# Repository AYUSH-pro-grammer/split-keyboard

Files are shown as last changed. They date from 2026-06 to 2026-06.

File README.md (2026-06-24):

# Split Keyboard

Split keyboard created in kicad and cad

## What is this project

This is a split keyboard. It is divided into 2 parts.
I designed it to gain some experience in pcb design, cad modeling and firmware development.
It has 22 keys per side, oled display, and rotary encoder.

## Why I made it

I want to design my own keyboard to gain experience in hardware project.
I got a lot of useful information about creating schematics, pcb routing, footprints, cad case modeling and file structure on github.

## what is inside

- split keyboard pcb
- cad case 
- firmware file
- gerber files
- project images
- bom csv

## Images

### Schematic Left

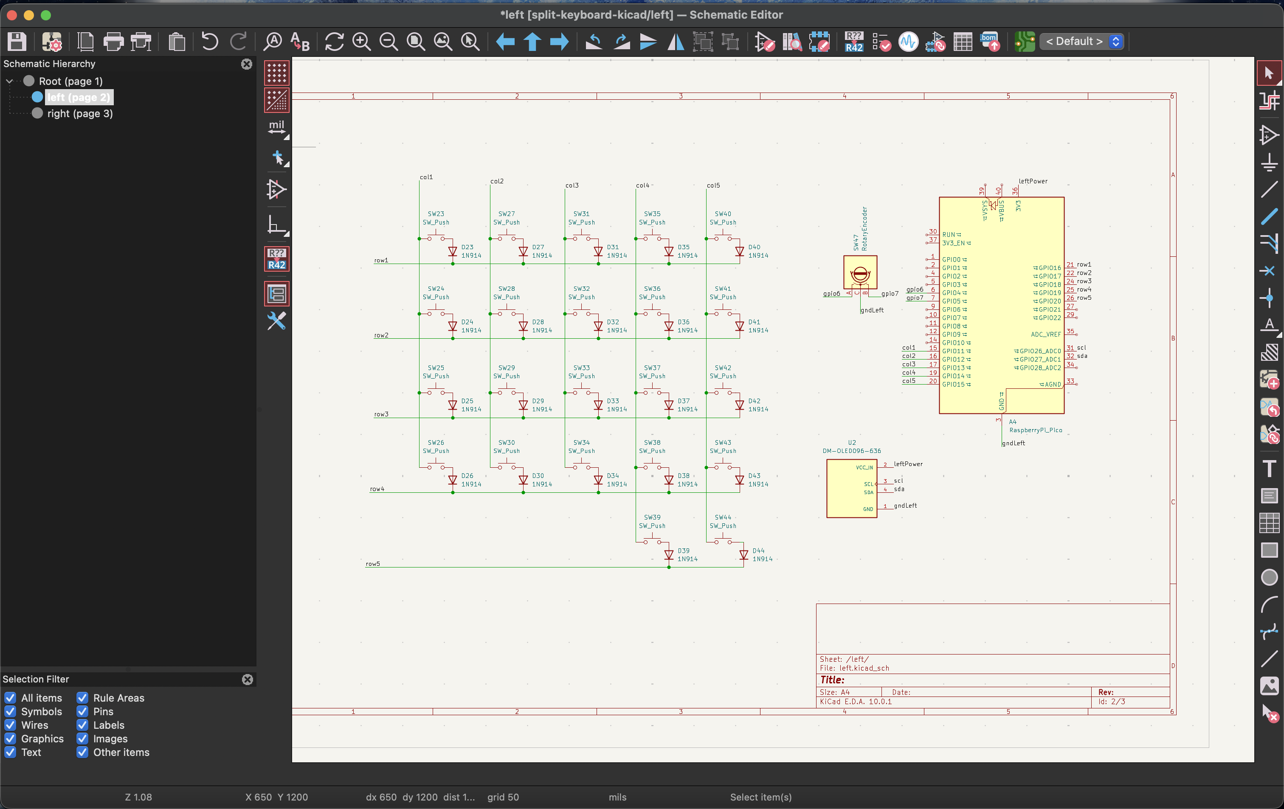
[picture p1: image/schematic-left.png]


### Schematic Right

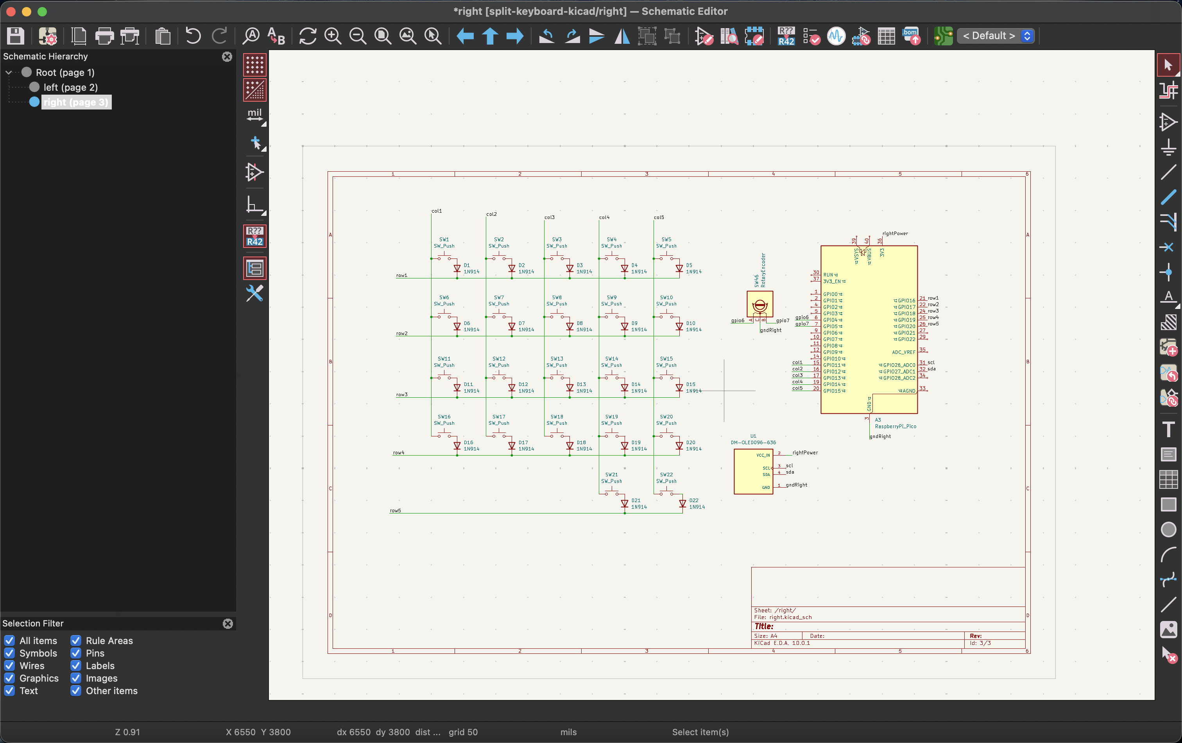
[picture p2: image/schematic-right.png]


### PCB Routing

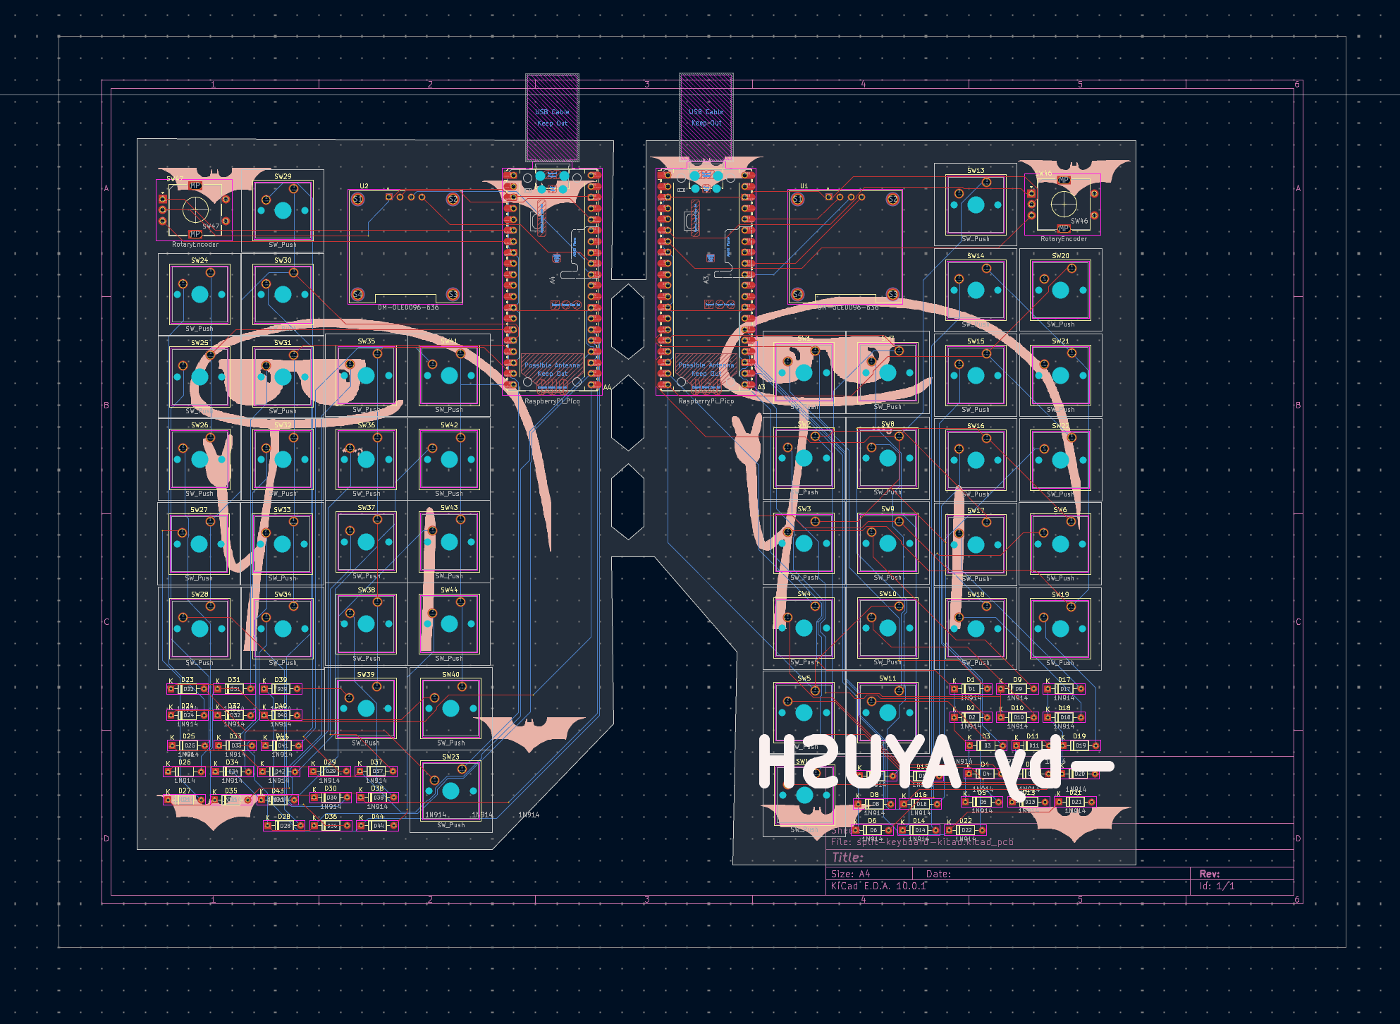
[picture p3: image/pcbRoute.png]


### PCB 3D Front

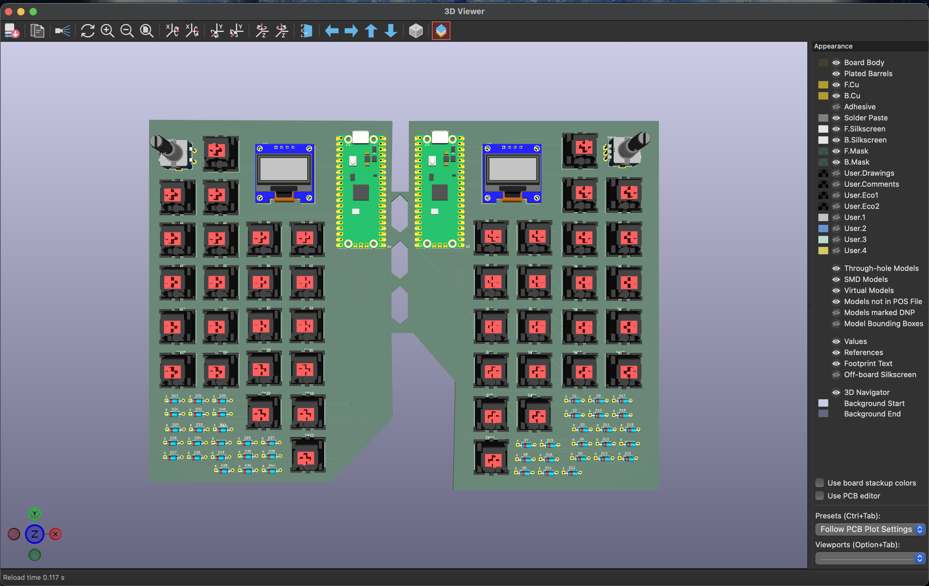
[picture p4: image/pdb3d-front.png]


### PCB 3D Back

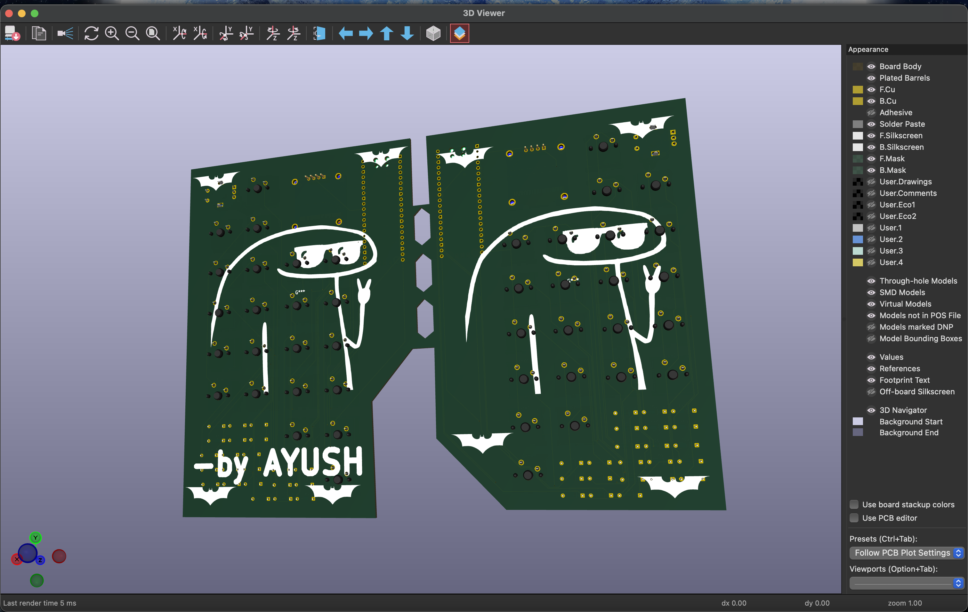
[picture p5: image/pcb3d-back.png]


### 3D 1

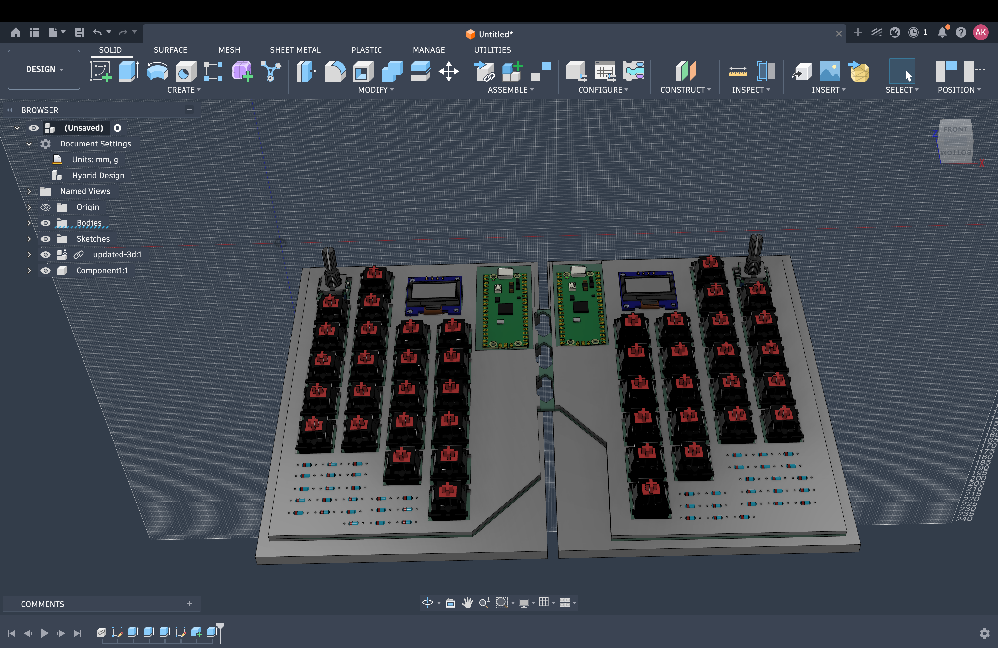
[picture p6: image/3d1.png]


### 3D 2

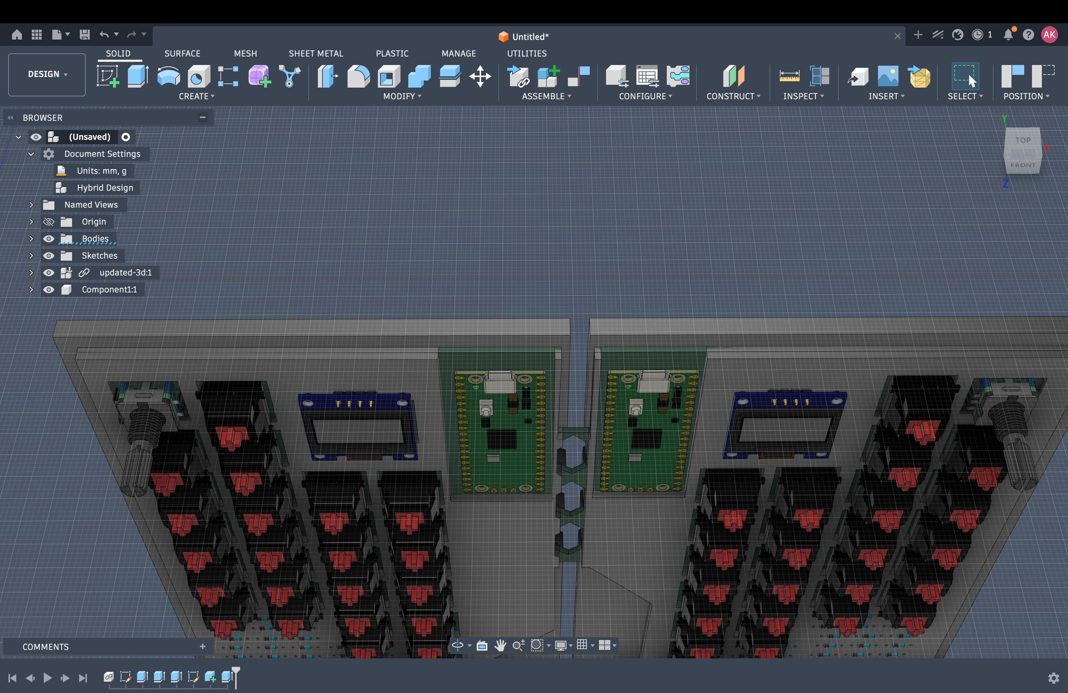
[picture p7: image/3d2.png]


### PCB Order

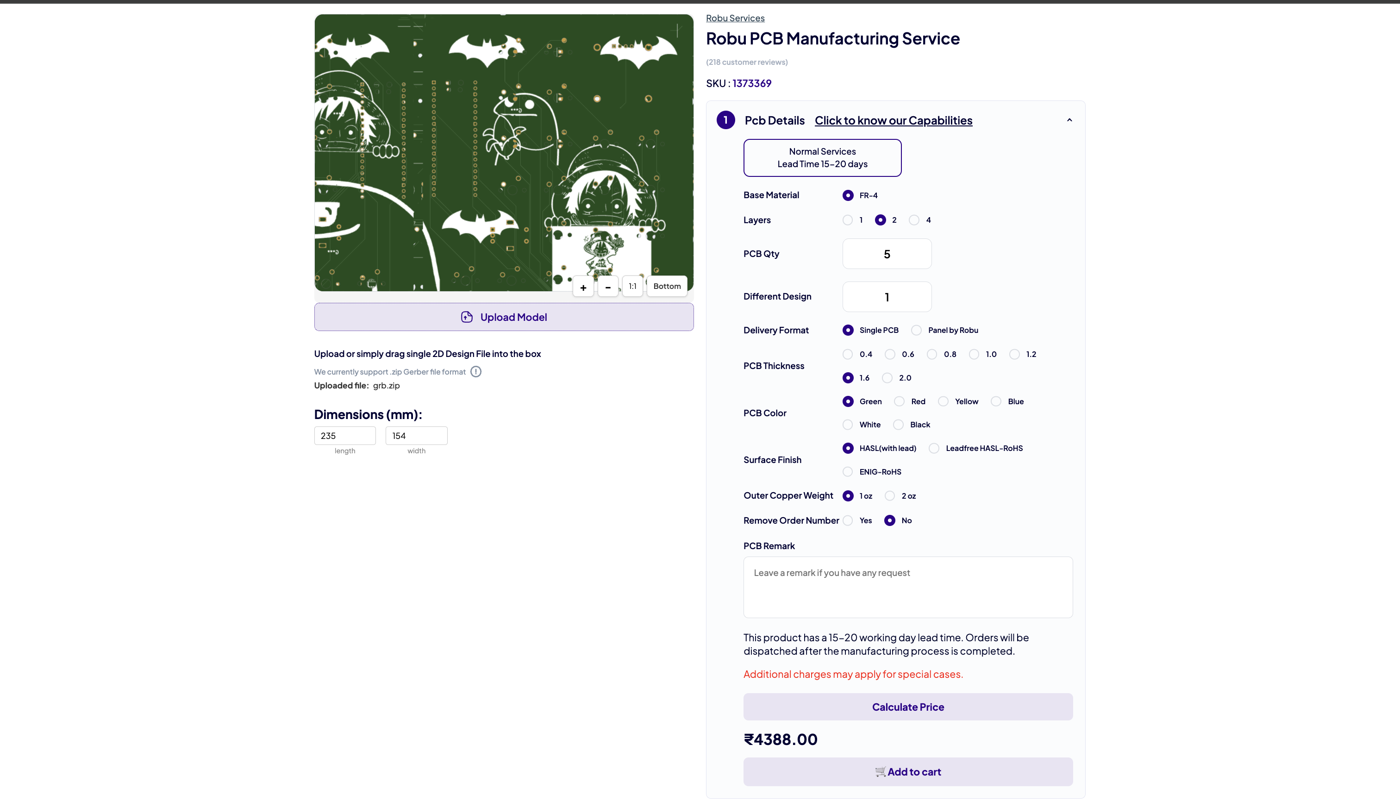
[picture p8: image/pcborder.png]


### Keycaps

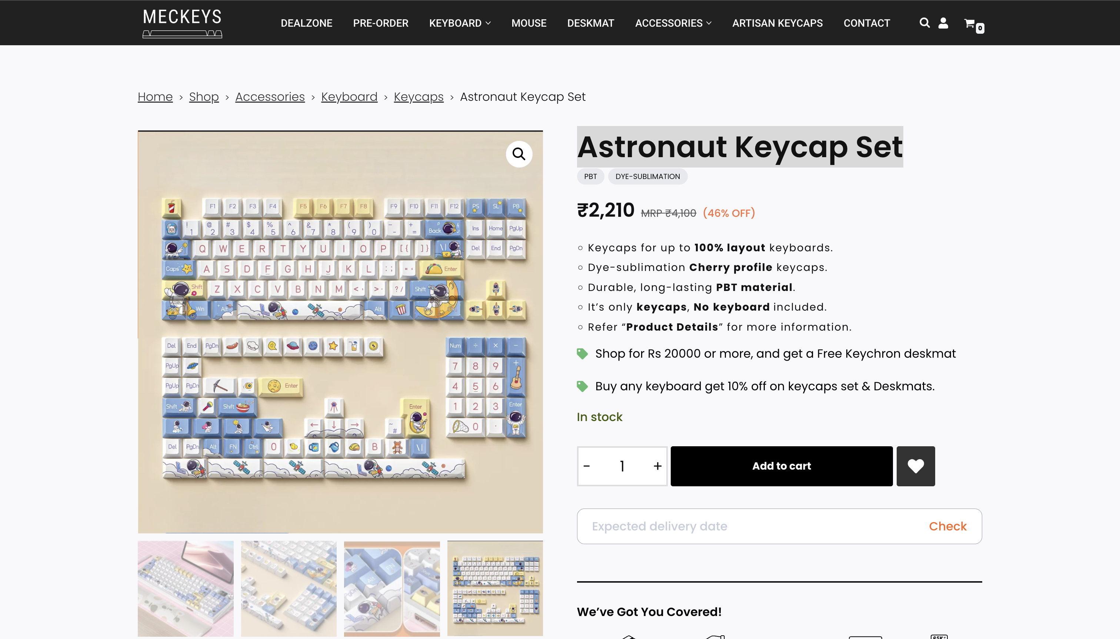
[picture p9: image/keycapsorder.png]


### Cherry MX Switches

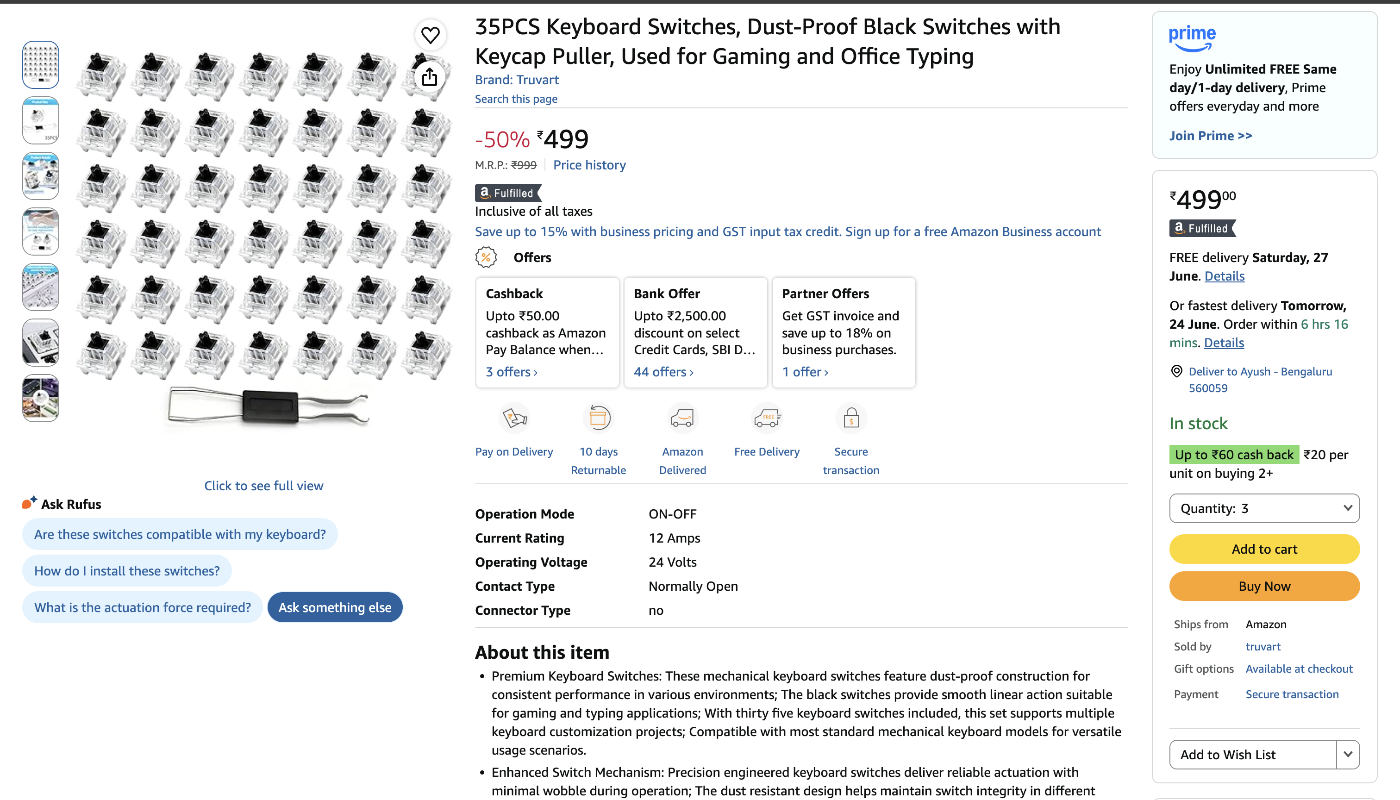
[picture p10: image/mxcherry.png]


### Repository Organization

```text
split-keyboard/
│
├── README.md
├── split-keyboard-bom.csv
│
├── cad/
│   ├── assembled.f3z
│   ├── assembled.step
│   └── pcb3d[pcb only].step
│
├── grb/
│   ├── split-keyboard-kicad-B_Cu.gbr
│   ├── split-keyboard-kicad-B_Mask.gbr
│   ├── split-keyboard-kicad-B_Paste.gbr
│   ├── split-keyboard-kicad-B_Silkscreen.gbr
│   ├── split-keyboard-kicad-Edge_Cuts.gbr
│   ├── split-keyboard-kicad-F_Cu.gbr
│   ├── split-keyboard-kicad-F_Mask.gbr
│   ├── split-keyboard-kicad-F_Paste.gbr
│   ├── split-keyboard-kicad-F_Silkscreen.gbr
│   ├── split-keyboard-kicad-NPTH.drl
│   ├── split-keyboard-kicad-PTH.drl
│   └── split-keyboard-kicad-job.gbr

```

## Features

* split keyboard design
* 22 keys on each side
* oled display
* 2 rotary encoders
* custom pcb designed in kicad
* custom cad case
* raspberry pi pico controller
* firmware written in c++

## 3D Model

### Full Keyboard Assembly

Full Keyboard Assembly

IMAGE COMMING SOONN AFTER BUILD...

this is the complete 3d model of the split keyboard with all major components placed inside the design. the model was created to verify the fit of the pcb, switches, display, rotary encoders, and case before manufacturing.

## Firmware

the firmware files for this project are available in the `split_keyboard_firmware/` folder.

currently the firmware is still being developed and tested. basic project structure, display examples, and source files have already been added to the repository.

## build notes

- i used kicad for my schematics and PCB design
- i designed the keyboard case in cad
- i exported gerber files for manufacture
- i kept the design simple to make it easy to build and code

## BOM

| Name | Purpose | Quantity | Total Cost (USD) | Link | Distributor |
| --- | --- | ---: | ---: | --- | --- |
| raspberry pi pico board | devboard to code on | 2 | $8.11 | https://robu.in/product/raspberry-pi-pico/ | robu |
| rotary encoder | knob control | 2 | $4.00 | https://robu.in/product/hongyan-ec11h-7ce15p1zy15f7-rotary-encoder-with-push-button-switch-vertical-plug-in/ | robu |
| pcb | to soilder all things onn | 1 | $46.00 | https://robu.in/product/online-pcb-manufacturing-service/ | robu |
| keycaps | to put above mx keys which give more surface area to click the button | 1 | $22.00 | https://meckeys.com/shop/accessories/keyboard-accessories/keycaps/astronaut-keycap-set/ | meckeys |
| mx cherry keys | to make button works, it is the buttons to press | 44 | $17.00 | https://www.amazon.in/Keyboard-Switches-Dust-Proof-Keycap-Puller/dp/B0GZVJZP6V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 | amazon |
| 1N4148 diodes | key matrix isolation | 44 | $3.00 | https://robu.in/product/diode-1n4148/ | robu |

## note

this project is still being worked on, and i will keep improving the case, layout, and code.

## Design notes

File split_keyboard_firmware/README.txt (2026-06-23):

Split Keyboard Firmware Package

File names:
- main.cpp      : Split keyboard firmware for a single Pico per half
- oled_demo.cpp : OLED demo sketch
- platformio.ini : PlatformIO Arduino project file

Pin configuration according to your schematic:
- Row pins: GPIO16, 17, 18, 19, 20
- Col pins: GPIO11, 12, 13, 14, 15
- Rotary encoder pins: GPIO6, GPIO7
- OLED I2C: GPIO26 = SCL, GPIO27 = SDA
- OLED address: 0x3C

Tips:
- Flash the same firmware on both Picos.
- Define SIDE_LEFT = 1 for the left half and 0 for the right half.
- It is easy to modify the keymap arrays if you have another keymap in mind.
- You need to switch the scanning mechanism in case of reverse diodes.

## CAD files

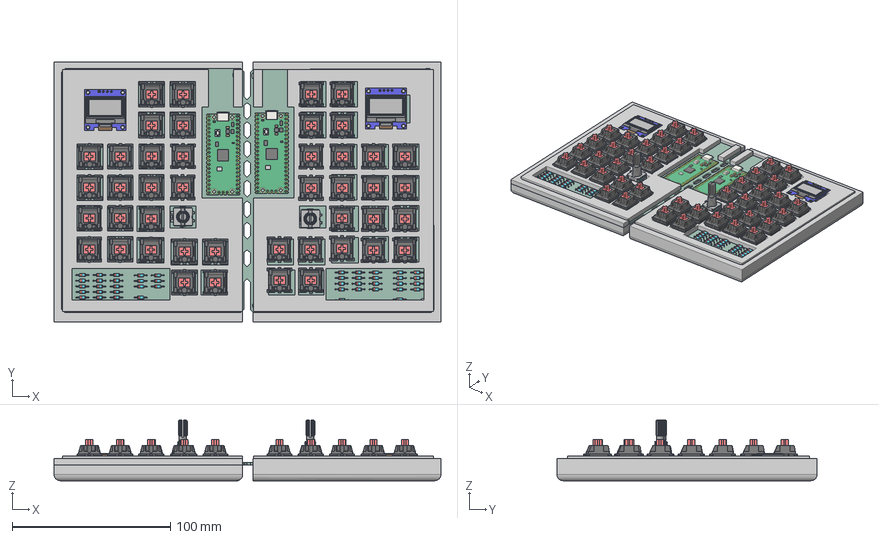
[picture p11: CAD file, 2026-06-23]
cad/assembled.step
244.3 x 164.2 x 38.2 mm

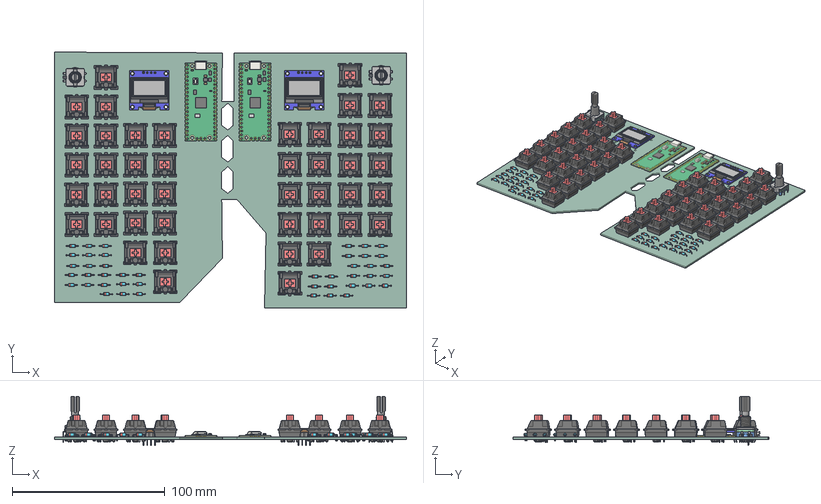
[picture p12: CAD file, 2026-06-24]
cad/3d-PCB-ONLY.step
230.5 x 167.5 x 32.3 mm
D_DO-35_SOD27_P7.62mm_Horizontal x 44
RaspberryPi_Pico_Module_KiCad x 2
DM-OLED096-636_Module x 2
DM-OLED096-636_Panel x 2
EC11_Rotary_Encoder_Switched x 2
split-keyboard-kicad_PCB

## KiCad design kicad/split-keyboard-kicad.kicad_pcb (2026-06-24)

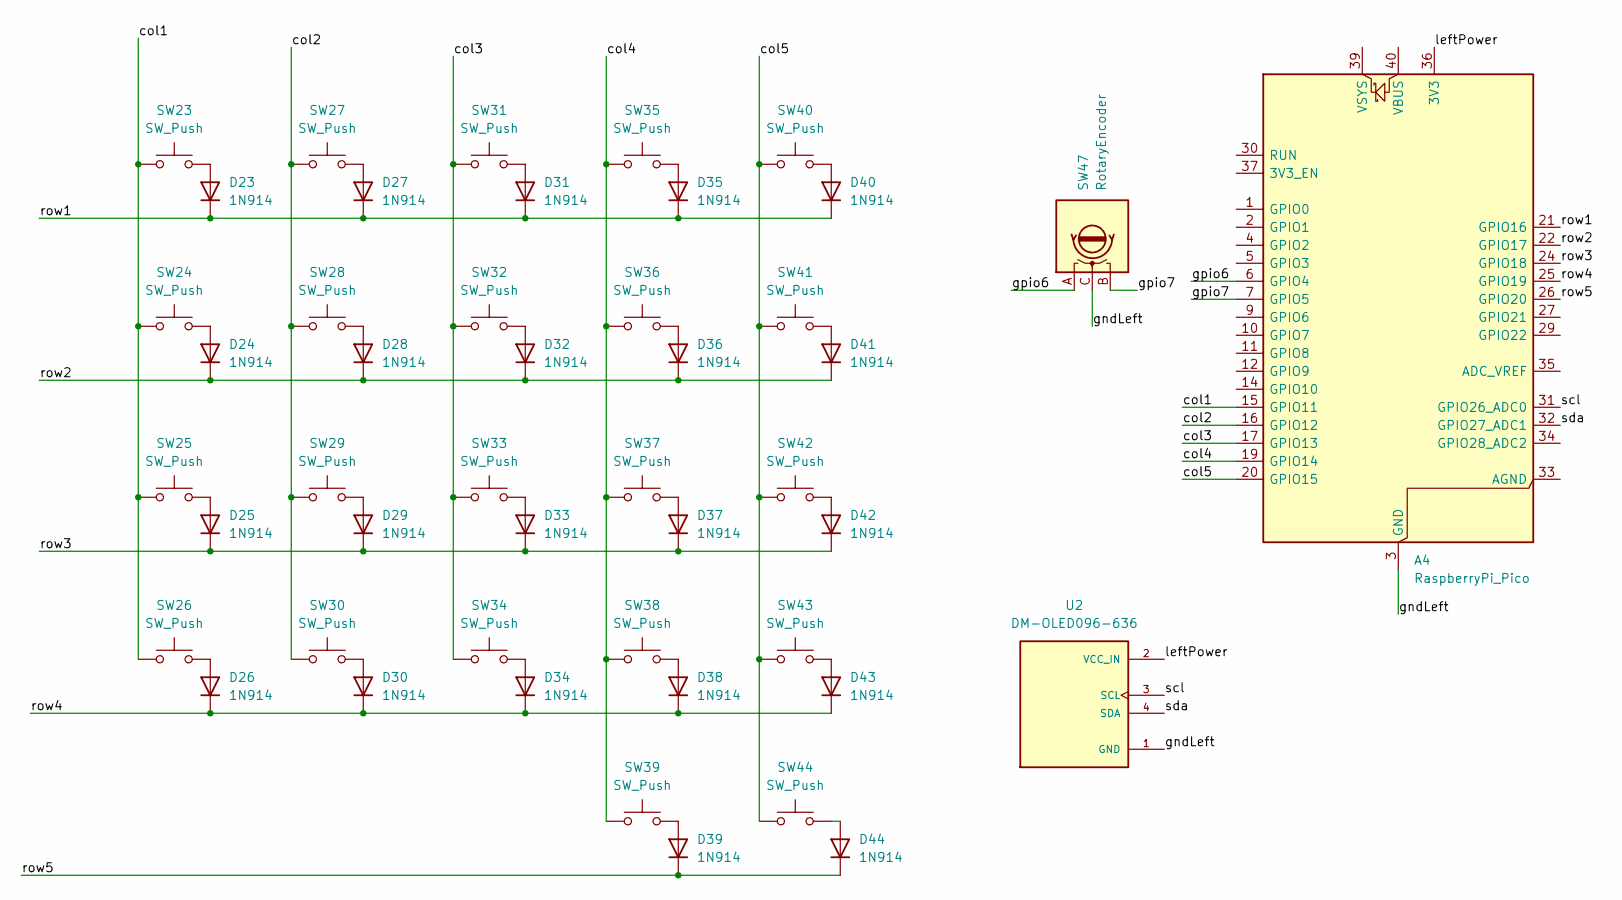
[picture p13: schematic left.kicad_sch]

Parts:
A4: RaspberryPi_Pico; RaspberryPi_Pico_Common_Unspecified
D23, D24, D25, D26, D27, D28, D29, D30, D31, D32, D33, D34, D35, D36, D37, D38, D39, D40, D41, D42, D43, D44: 1N914; D_DO-35_SOD27_P7.62mm_Horizontal
SW23, SW24, SW25, SW26, SW27, SW28, SW29, SW30, SW31, SW32, SW33, SW34, SW35, SW36, SW37, SW38, SW39, SW40, SW41, SW42, SW43, SW44: SW_Push; SW_Cherry_MX_1.00u_PCB
SW47: RotaryEncoder; RotaryEncoder_Alps_EC11E-Switch_Vertical_H20mm
U2: DM-OLED096-636; MODULE_DM-OLED096-636; PARTREV 2018-09-10

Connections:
/left/col1: A4.15 (GPIO11), SW23.1, SW24.1, SW25.1, SW26.1
/left/col2: A4.16 (GPIO12), SW27.1, SW28.1, SW29.1, SW30.1
/left/col3: A4.17 (GPIO13), SW31.1, SW32.1, SW33.1, SW34.1
/left/col4: A4.19 (GPIO14), SW35.1, SW36.1, SW37.1, SW38.1, SW39.1
/left/col5: A4.20 (GPIO15), SW40.1, SW41.1, SW42.1, SW43.1, SW44.1
/left/gndLeft: A4.3 (GND), A4.8 (GND), A4.13 (GND), A4.18 (GND), A4.23 (GND), A4.28 (GND), A4.38 (GND), SW47.C, U2.1 (GND)
/left/gpio6: A4.6 (GPIO4), SW47.A
/left/gpio7: A4.7 (GPIO5), SW47.B
/left/leftPower: A4.36 (3V3), U2.2 (VCC_IN)
/left/row1: A4.21 (GPIO16), D23.1 (K), D27.1 (K), D31.1 (K), D35.1 (K), D40.1 (K)
/left/row2: A4.22 (GPIO17), D24.1 (K), D28.1 (K), D32.1 (K), D36.1 (K), D41.1 (K)
/left/row3: A4.24 (GPIO18), D25.1 (K), D29.1 (K), D33.1 (K), D37.1 (K), D42.1 (K)
/left/row4: A4.25 (GPIO19), D26.1 (K), D30.1 (K), D34.1 (K), D38.1 (K), D43.1 (K)
/left/row5: A4.26 (GPIO20), D39.1 (K), D44.1 (K)
/left/scl: A4.31 (GPIO26_ADC0), U2.3 (SCL)
/left/sda: A4.32 (GPIO27_ADC1), U2.4 (SDA)
unnamed: D23.2 (A), SW23.2
unnamed: D24.2 (A), SW24.2
unnamed: D25.2 (A), SW25.2
unnamed: D26.2 (A), SW26.2
unnamed: D27.2 (A), SW27.2
unnamed: D28.2 (A), SW28.2
unnamed: D29.2 (A), SW29.2
unnamed: D30.2 (A), SW30.2
unnamed: D31.2 (A), SW31.2
unnamed: D32.2 (A), SW32.2
unnamed: D33.2 (A), SW33.2
unnamed: D34.2 (A), SW34.2
unnamed: D35.2 (A), SW35.2
unnamed: D36.2 (A), SW36.2
unnamed: D37.2 (A), SW37.2
unnamed: D38.2 (A), SW38.2
unnamed: D39.2 (A), SW39.2
unnamed: D40.2 (A), SW40.2
unnamed: D41.2 (A), SW41.2
unnamed: D42.2 (A), SW42.2
unnamed: D43.2 (A), SW43.2
unnamed: D44.2 (A), SW44.2

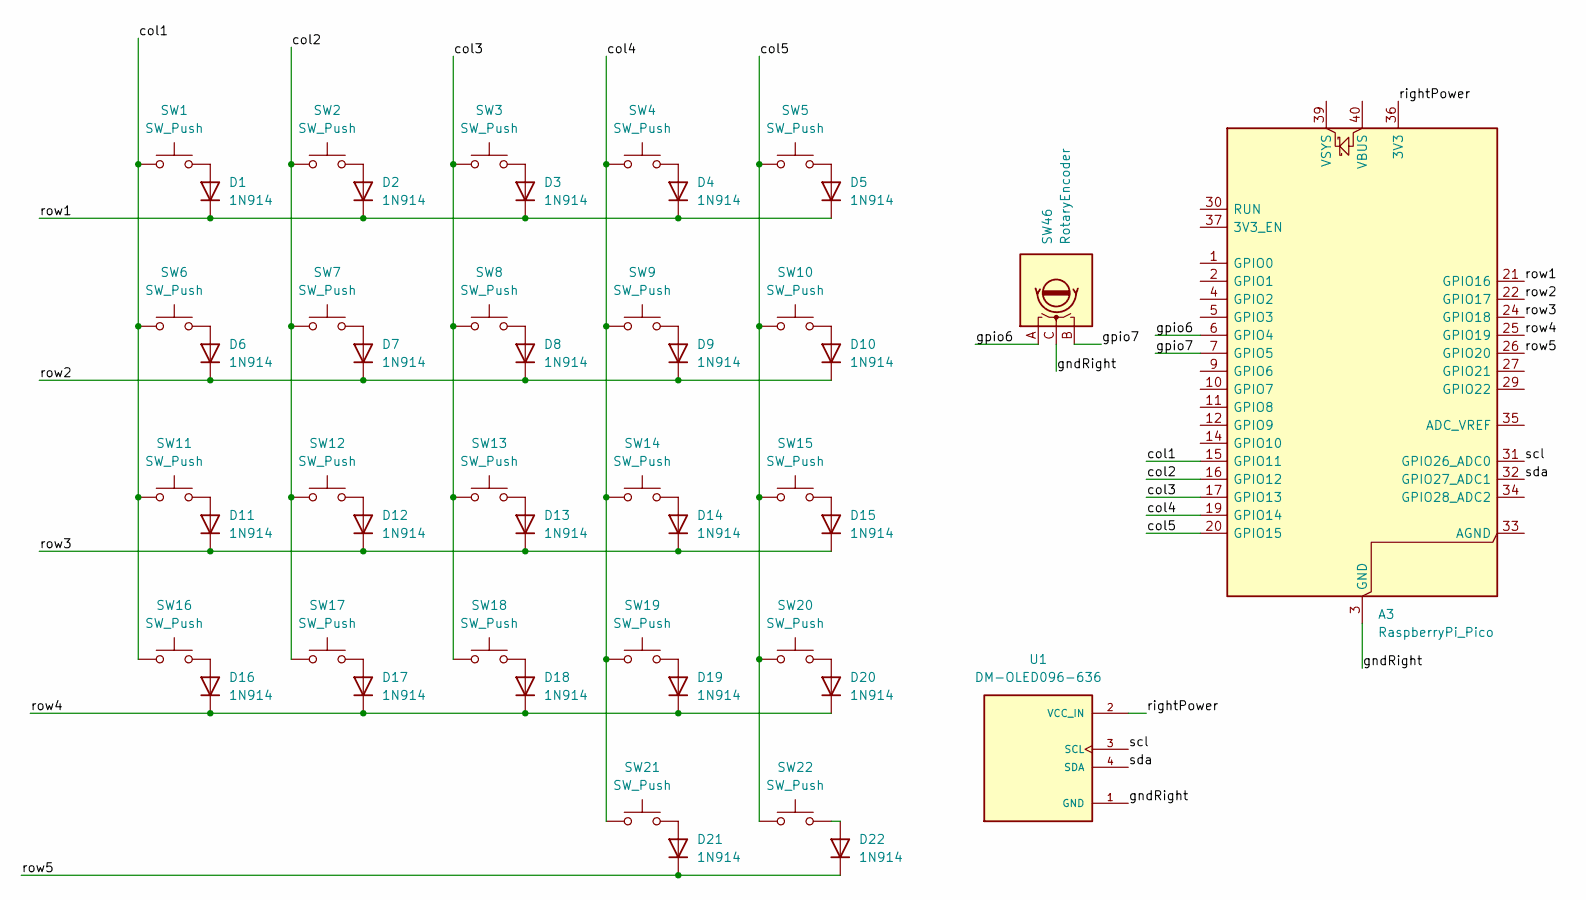
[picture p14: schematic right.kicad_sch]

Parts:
A3: RaspberryPi_Pico; RaspberryPi_Pico_Common_Unspecified
D1, D2, D3, D4, D5, D6, D7, D8, D9, D10, D11, D12, D13, D14, D15, D16, D17, D18, D19, D20, D21, D22: 1N914; D_DO-35_SOD27_P7.62mm_Horizontal
SW1, SW2, SW3, SW4, SW5, SW6, SW7, SW8, SW9, SW10, SW11, SW12, SW13, SW14, SW15, SW16, SW17, SW18, SW19, SW20, SW21, SW22: SW_Push; SW_Cherry_MX_1.00u_PCB
SW46: RotaryEncoder; RotaryEncoder_Alps_EC11E-Switch_Vertical_H20mm
U1: DM-OLED096-636; MODULE_DM-OLED096-636; PARTREV 2018-09-10

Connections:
/right/col1: A3.15 (GPIO11), SW1.1, SW6.1, SW11.1, SW16.1
/right/col2: A3.16 (GPIO12), SW2.1, SW7.1, SW12.1, SW17.1
/right/col3: A3.17 (GPIO13), SW3.1, SW8.1, SW13.1, SW18.1
/right/col4: A3.19 (GPIO14), SW4.1, SW9.1, SW14.1, SW19.1, SW21.1
/right/col5: A3.20 (GPIO15), SW5.1, SW10.1, SW15.1, SW20.1, SW22.1
/right/gndRight: A3.3 (GND), A3.8 (GND), A3.13 (GND), A3.18 (GND), A3.23 (GND), A3.28 (GND), A3.38 (GND), SW46.C, U1.1 (GND)
/right/gpio6: A3.6 (GPIO4), SW46.A
/right/gpio7: A3.7 (GPIO5), SW46.B
/right/rightPower: A3.36 (3V3), U1.2 (VCC_IN)
/right/row1: A3.21 (GPIO16), D1.1 (K), D2.1 (K), D3.1 (K), D4.1 (K), D5.1 (K)
/right/row2: A3.22 (GPIO17), D6.1 (K), D7.1 (K), D8.1 (K), D9.1 (K), D10.1 (K)
/right/row3: A3.24 (GPIO18), D11.1 (K), D12.1 (K), D13.1 (K), D14.1 (K), D15.1 (K)
/right/row4: A3.25 (GPIO19), D16.1 (K), D17.1 (K), D18.1 (K), D19.1 (K), D20.1 (K)
/right/row5: A3.26 (GPIO20), D21.1 (K), D22.1 (K)
/right/scl: A3.31 (GPIO26_ADC0), U1.3 (SCL)
/right/sda: A3.32 (GPIO27_ADC1), U1.4 (SDA)
unnamed: D1.2 (A), SW1.2
unnamed: D2.2 (A), SW2.2
unnamed: D3.2 (A), SW3.2
unnamed: D4.2 (A), SW4.2
unnamed: D5.2 (A), SW5.2
unnamed: D6.2 (A), SW6.2
unnamed: D7.2 (A), SW7.2
unnamed: D8.2 (A), SW8.2
unnamed: D9.2 (A), SW9.2
unnamed: D10.2 (A), SW10.2
unnamed: D11.2 (A), SW11.2
unnamed: D12.2 (A), SW12.2
unnamed: D13.2 (A), SW13.2
unnamed: D14.2 (A), SW14.2
unnamed: D15.2 (A), SW15.2
unnamed: D16.2 (A), SW16.2
unnamed: D17.2 (A), SW17.2
unnamed: D18.2 (A), SW18.2
unnamed: D19.2 (A), SW19.2
unnamed: D20.2 (A), SW20.2
unnamed: D21.2 (A), SW21.2
unnamed: D22.2 (A), SW22.2

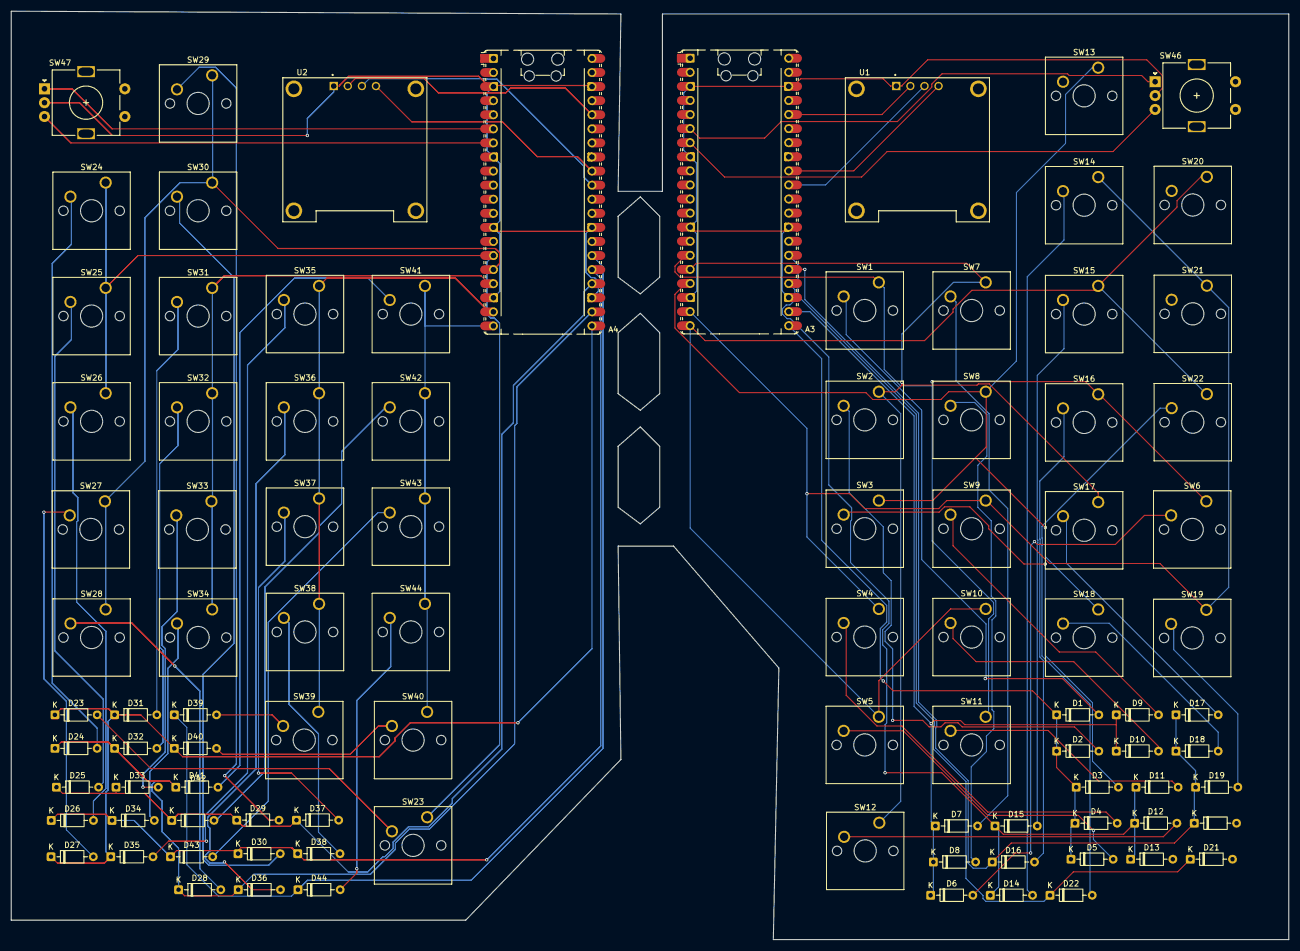
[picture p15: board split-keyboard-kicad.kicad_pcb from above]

Board: 2 copper layers, 230.5 x 167.5 mm, 94 parts (0 on the bottom side), 76 nets.

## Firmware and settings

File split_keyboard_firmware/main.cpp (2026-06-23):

#include <Arduino.h>
#include <Keyboard.h>
#include <Wire.h>
#include <Adafruit_GFX.h>
#include <Adafruit_SSD1306.h>

/*
Split Keyboard Firmware Package

File names:
- main.cpp      : Split keyboard firmware for a single Pico per half
- oled_demo.cpp : OLED demo sketch
- platformio.ini : PlatformIO Arduino project file

Pin configuration according to your schematic:
- Row pins: GPIO16, 17, 18, 19, 20
- Col pins: GPIO11, 12, 13, 14, 15
- Rotary encoder pins: GPIO6, GPIO7
- OLED I2C: GPIO26 = SCL, GPIO27 = SDA
- OLED address: 0x3C

*/

#define SIDE_LEFT 1

static constexpr uint8_t ROWS = 5;
static constexpr uint8_t COLS = 5;
static constexpr uint8_t DEBOUNCE_MS = 18;

static constexpr uint8_t ROW_PINS[ROWS] = {16, 17, 18, 19, 20};
static constexpr uint8_t COL_PINS[COLS] = {11, 12, 13, 14, 15};

static constexpr uint8_t ENC_A = 6;
static constexpr uint8_t ENC_B = 7;

static constexpr uint8_t OLED_SDA = 27;
static constexpr uint8_t OLED_SCL = 26;
static constexpr uint8_t OLED_ADDR = 0x3C;

static constexpr int SCREEN_W = 128;
static constexpr int SCREEN_H = 64;

Adafruit_SSD1306 display(SCREEN_W, SCREEN_H, &Wire, -1);

struct DebouncedKey {
  bool raw = false;
  bool stable = false;
  uint32_t changed_at = 0;
};

static DebouncedKey keys[ROWS][COLS];
static bool oled_ok = false;
static uint32_t last_oled = 0;
static uint32_t last_scan = 0;

static int32_t encoder_steps = 0;
static int32_t encoder_detents = 0;
static uint8_t enc_prev = 0;

static char last_key_label[16] = "none";
static uint16_t active_keys = 0;
static uint16_t total_presses = 0;

// Common split layout; edit only these arrays to match your preferred keymap.
static const uint8_t keymap_left[ROWS][COLS] = {
  { 'q', 'w', 'e', 'r', 't' },
  { 'a', 's', 'd', 'f', 'g' },
  { 'z', 'x', 'c', 'v', 'b' },
  { KEY_LEFT_CTRL, KEY_LEFT_GUI, KEY_LEFT_ALT, ' ', KEY_BACKSPACE },
  { 0, 0, 0, KEY_ESC, KEY_TAB },
};

static const uint8_t keymap_right[ROWS][COLS] = {
  { 'y', 'u', 'i', 'o', 'p' },
  { 'h', 'j', 'k', 'l', ';' },
  { 'n', 'm', ',', '.', '/' },
  { KEY_LEFT_SHIFT, KEY_RETURN, KEY_DELETE, KEY_UP_ARROW, KEY_DOWN_ARROW },
  { 0, 0, 0, KEY_PAGE_UP, KEY_PAGE_DOWN },
};

static inline const uint8_t (*active_keymap())[COLS] {
  return SIDE_LEFT ? keymap_left : keymap_right;
}

static const char* side_name() {
  return SIDE_LEFT ? "LEFT" : "RIGHT";
}

static void setLastKeyLabel(uint8_t code, bool down) {
  if (code == 0) {
    snprintf(last_key_label, sizeof(last_key_label), "unused");
    return;
  }

  if (code >= 32 && code <= 126) {
    snprintf(last_key_label, sizeof(last_key_label), "%c %s", (char)code, down ? "dn" : "up");
    return;
  }

  switch (code) {
    case KEY_RETURN:       snprintf(last_key_label, sizeof(last_key_label), "ENTER %s", down ? "dn" : "up"); break;
    case KEY_ESC:          snprintf(last_key_label, sizeof(last_key_label), "ESC %s", down ? "dn" : "up"); break;
    case KEY_TAB:          snprintf(last_key_label, sizeof(last_key_label), "TAB %s", down ? "dn" : "up"); break;
    case KEY_BACKSPACE:    snprintf(last_key_label, sizeof(last_key_label), "BSPC %s", down ? "dn" : "up"); break;
    case KEY_DELETE:       snprintf(last_key_label, sizeof(last_key_label), "DEL %s", down ? "dn" : "up"); break;
    case KEY_PAGE_UP:      snprintf(last_key_label, sizeof(last_key_label), "PGUP %s", down ? "dn" : "up"); break;
    case KEY_PAGE_DOWN:    snprintf(last_key_label, sizeof(last_key_label), "PGDN %s", down ? "dn" : "up"); break;
    case KEY_LEFT_CTRL:    snprintf(last_key_label, sizeof(last_key_label), "LCTRL %s", down ? "dn" : "up"); break;
    case KEY_LEFT_SHIFT:   snprintf(last_key_label, sizeof(last_key_label), "LSHFT %s", down ? "dn" : "up"); break;
    case KEY_LEFT_ALT:     snprintf(last_key_label, sizeof(last_key_label), "LALT %s", down ? "dn" : "up"); break;
    case KEY_LEFT_GUI:     snprintf(last_key_label, sizeof(last_key_label), "LGUI %s", down ? "dn" : "up"); break;
    case KEY_UP_ARROW:     snprintf(last_key_label, sizeof(last_key_label), "UP %s", down ? "dn" : "up"); break;
    case KEY_DOWN_ARROW:   snprintf(last_key_label, sizeof(last_key_label), "DOWN %s", down ? "dn" : "up"); break;
    case KEY_LEFT_ARROW:   snprintf(last_key_label, sizeof(last_key_label), "LEFT %s", down ? "dn" : "up"); break;
    case KEY_RIGHT_ARROW:  snprintf(last_key_label, sizeof(last_key_label), "RIGHT %s", down ? "dn" : "up"); break;
    default:               snprintf(last_key_label, sizeof(last_key_label), "KC%u %s", code, down ? "dn" : "up"); break;
  }
}

static void pressKey(uint8_t code) {
  if (code == 0) return;
  Keyboard.press(code);
  total_presses++;
  setLastKeyLabel(code, true);
}

static void releaseKey(uint8_t code) {
  if (code == 0) return;
  Keyboard.release(code);
  setLastKeyLabel(code, false);
}

static void handleKeyChange(uint8_t row, uint8_t col, bool pressed) {
  const uint8_t code = active_keymap()[row][col];
  if (pressed) pressKey(code);
  else releaseKey(code);
}

static uint16_t countActiveKeys() {
  uint16_t count = 0;
  for (uint8_t r = 0; r < ROWS; ++r) {
    for (uint8_t c = 0; c < COLS; ++c) {
      if (keys[r][c].stable) ++count;
    }
  }
  return count;
}

static void initMatrix() {
  for (uint8_t r = 0; r < ROWS; ++r) {
    pinMode(ROW_PINS[r], OUTPUT);
    digitalWrite(ROW_PINS[r], HIGH);
  }
  for (uint8_t c = 0; c < COLS; ++c) {
    pinMode(COL_PINS[c], INPUT_PULLUP);
  }
}

static void initEncoder() {
  pinMode(ENC_A, INPUT_PULLUP);
  pinMode(ENC_B, INPUT_PULLUP);
  enc_prev = (digitalRead(ENC_A) << 1) | digitalRead(ENC_B);
}

static void initOLED() {
  Wire.setSDA(OLED_SDA);
  Wire.setSCL(OLED_SCL);
  Wire.begin();

  oled_ok = display.begin(SSD1306_SWITCHCAPVCC, OLED_ADDR);
  if (!oled_ok) return;

  display.clearDisplay();
  display.setTextSize(1);
  display.setTextColor(SSD1306_WHITE);
  display.setCursor(0, 0);
  display.print("Split keyboard");
  display.setCursor(0, 12);
  display.print(side_name());
  display.display();
}

static void drawOLED() {
  if (!oled_ok) return;

  display.clearDisplay();
  display.setTextSize(1);
  display.setTextColor(SSD1306_WHITE);

  display.setCursor(0, 0);
  display.print("Split keyboard");
  display.setCursor(0, 10);
  display.print("Side: ");
  display.print(side_name());

  display.setCursor(0, 20);
  display.print("Active: ");
  display.print(active_keys);

  display.setCursor(0, 30);
  display.print("Enc: ");
  display.print(encoder_detents);

  display.setCursor(0, 40);
  display.print("Keys: ");
  display.print(total_presses);

  display.setCursor(0, 52);
  display.print(last_key_label);

  // tiny animation
  uint8_t x = (millis() / 18) % 104;
  display.drawRect(x, 56, 24, 6, SSD1306_WHITE);
  display.fillRect(x + 2, 58, 10, 2, SSD1306_WHITE);

  display.display();
}

static void scanEncoder() {
  // Simple quadrature decode with detent accumulation.
  static const int8_t lut[16] = {
    0, -1,  1,  0,
    1,  0,  0, -1,
   -1,  0,  0,  1,
    0,  1, -1,  0
  };

  const uint8_t curr = (digitalRead(ENC_A) << 1) | digitalRead(ENC_B);
  const uint8_t idx = (enc_prev << 2) | curr;
  const int8_t delta = lut[idx];
  enc_prev = curr;

  if (delta == 0) return;

  encoder_steps += delta;

  // four transitions per detent on most EC11-style encoders
  if (encoder_steps >= 4) {
    encoder_steps = 0;
    encoder_detents++;
    Keyboard.write(KEY_PAGE_UP);
    snprintf(last_key_label, sizeof(last_key_label), "ENC cw");
  } else if (encoder_steps <= -4) {
    encoder_steps = 0;
    encoder_detents--;
    Keyboard.write(KEY_PAGE_DOWN);
    snprintf(last_key_label, sizeof(last_key_label), "ENC ccw");
  }
}

static void scanMatrix() {
  const uint32_t now = millis();

  for (uint8_t r = 0; r < ROWS; ++r) {
    digitalWrite(ROW_PINS[r], LOW);
    delayMicroseconds(5);

    for (uint8_t c = 0; c < COLS; ++c) {
      const bool raw_pressed = (digitalRead(COL_PINS[c]) == LOW);

      DebouncedKey &k = keys[r][c];
      if (raw_pressed != k.raw) {
        k.raw = raw_pressed;
        k.changed_at = now;
      }

      if ((now - k.changed_at) >= DEBOUNCE_MS && k.stable != k.raw) {
        k.stable = k.raw;
        handleKeyChange(r, c, k.stable);
      }
    }

    digitalWrite(ROW_PINS[r], HIGH);
  }

  active_keys = countActiveKeys();
}

void setup() {
  delay(300);
  Keyboard.begin();

  initMatrix();
  initEncoder();
  initOLED();

  last_scan = millis();
}

void loop() {
  scanMatrix();
  scanEncoder();

  if (millis() - last_oled >= 80) {
    last_oled = millis();
    drawOLED();
  }

  // If you want to reduce CPU use a little:
  delay(1);
}

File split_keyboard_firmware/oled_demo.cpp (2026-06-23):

#include <Arduino.h>
#include <Wire.h>
#include <Adafruit_GFX.h>
#include <Adafruit_SSD1306.h>

static constexpr uint8_t kSDApin = 27;
static constexpr uint8_t kSCLpin = 26;
static constexpr uint8_t kI2Caddr = 0x3C;

static constexpr int kW = 128;
static constexpr int kH = 64;

Adafruit_SSD1306 scr(kW, kH, &Wire, -1);

void setup() {
  Wire.setSDA(kSDApin);
  Wire.setSCL(kSCLpin);
  Wire.begin();

  scr.begin(SSD1306_SWITCHCAPVCC, kI2Caddr);

  scr.clearDisplay();
  scr.setTextColor(SSD1306_WHITE);
  scr.setTextSize(1);
  scr.setCursor(0, 0);

  scr.println("OLED test");
  scr.println("Split keyboard");
  scr.println("GP26 SCL");
  scr.println("GP27 SDA");
  scr.display();

  delay(1200);
}

void loop() {
  static int wPos = 0;
  static int step = 1;
  static uint32_t tPrev = 0;

  if (millis() - tPrev < 25) return;
  tPrev = millis();

  scr.clearDisplay();
  scr.setTextSize(1);
  scr.setCursor(0, 0);

  scr.println("OLED test");
  scr.println("Connection OK");

  scr.drawRect(wPos, 28, 20, 10, SSD1306_WHITE);
  scr.fillCircle((wPos + 10) % 128, 52, 4, SSD1306_WHITE);

  scr.setCursor(0, 56);
  scr.print("GP26/27");

  scr.display();

  wPos += step;
  if (wPos <= 0 || wPos >= 108) step = -step;
}

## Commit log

2026-06-23 added all
    [assembled.f3z, assembled.step, left.kicad_sch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]
2026-06-23 updated csv
    [split-keyboard-bom.csv]
